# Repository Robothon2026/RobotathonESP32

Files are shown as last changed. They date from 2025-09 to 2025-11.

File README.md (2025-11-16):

# Robotathon ESP32
----Alternative Movement----
There are two different movement styles. Test both and see which feels better overall. 
1. Left joystick->left motor (current)
   Right joystick->right motor
2. Left joystick->both motors (commented out)
   Right joystick-> adjusts one side depending on x position

---- Line Automation----
 If correction is negative, move left by adjusting the left wheel slower while adjusitng the right wheel faster
 if correction is positive, move right by adjusting the right wheel slower while adjusitng the left wheel faster
 if correction is zero, move straight forward at full speed
 I decided to not use the invert sensors function because it is easers to just use 1,000 for black and 0 for white
 as if i use it the other way i would have to invert everything and also i wouldn't know how that would be able to work becuase
 *right now the lineHelper function works by multiplying the sensor values by the weights but if its 1,000 in the middle and 0 on white
 then the error would go based off the middle which i dont think would be as effecient and just more complicated then using 0
 for white and 1,000 for black

----Color Automation----
How to control
1. Switch to color automation.
2. Put robot over sample color.
4. It will continue to move until it finds the color again.

----Wall Automation----
This automation part is heavily heavily heavily dependant on thresholds.
Before even attempting, you have to ensure multiple different things work together.
1. I created TIME_90_DEGREES.
   You need to debug and find how long these numbers need to be for the robot to actually rotate 90 degrees. There's no actual way to tell the robot to turn a certain degree it has to be done manually.
2. In the wallAutomation() method, there are several variables you need to test as well.
   a. wallThreshold: This is the number (cm) until the robot should treat it as a wall.
   b. rightThreshold: This is the number (cm) that tells you how far it is from the right wall.
   c. speedAdjust: This is how much the motor will slow down when it's readjusting within walls.
   1. if no wall in front, move forward.
   2. If wall in front, check right sensor, if open path, rotate 90 degrees clockwise.
   3. Else (wall on right), rotate 90 degrees counter clockwise.
           Algorithm A: While moving forward, it should stay within the right bounds. If it's 
               within these bounds, just move forward. It may still drift a bit, but that's okay.
               If it's minor, I'll leave as is. If it's major, then I'll implement PD control
               to adjust the motors based off previous value. If it is out of these bounds, then
               adjust motors based off set values (not changing).
           Algorithm B: Just move forward without worrying about centering. If rotate90CW/CCW is
               implemented well enough, then no adjustments should be necessary.
           Algorithm C: Combination of A and B. Move forward normally, but before turning 90 degrees, 
               if previous right distance > current right distance, (getting closer to wall), then
               adjust delay for TIME_90_DEGREES so that it turns for longer. If previous right
               distance < current right distance, (getting farther away from wall), then adjust
               delay for TIME_90_DEGREES so that it turns for less time.
           Notes: Calculate the connection between delay time and angle turned. Use that to adjust
               TIME_90_DEGREES based off previous and current. Calculate previous and current by
               and make them a set time apart TIME_90_DEGREES. You can then use these two to create 
               a triangle and figure out the angle it's currently moving at. From there, you can 
               calculate how much to turn to be parallel to the wall after a turn. This assumes it 
               never hits the wall which should stand true, if not there's an error in the logic. 
               The delta time is TIME_90_DEGREES because you use this to turn 90 degrees, so after 
               calculating the angle you can easily figure out how much you need to adjust to stay 
               parallel.

----Notes----
2. Adjust color offset delay so robot is over the color. 
4. I use TOP_MOTOR_SPEED for a lot of things. Don't change this variable but make another one if you think it's too fast.
5. Calculate size of wheel and radius and create equation to automatically see how long it takes to do 90 degrees.
6. Design robot so it keeps turning towards the right and then it stops when its close enough (threshold).
7. Remove left sensor integration.

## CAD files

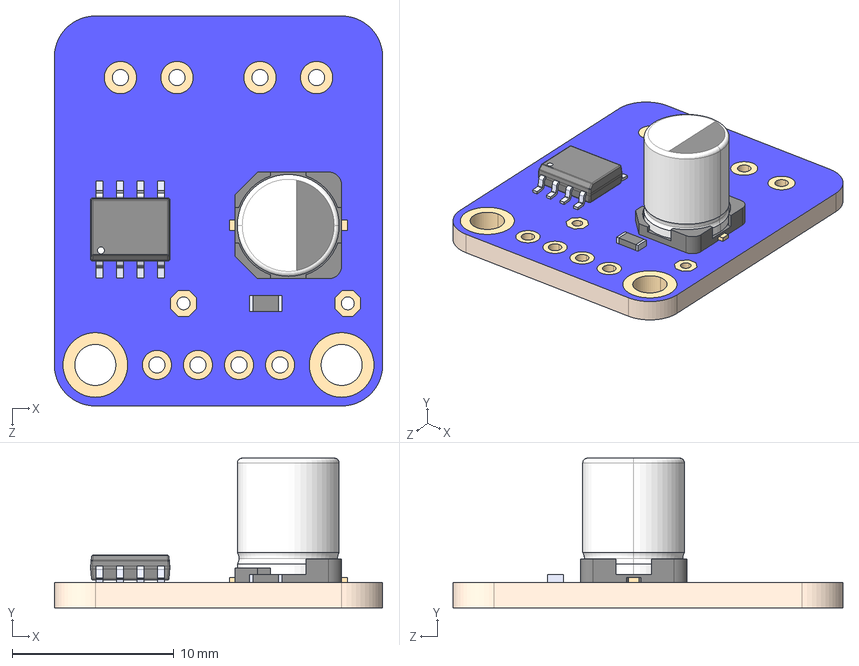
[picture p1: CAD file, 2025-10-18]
Robotathon_kicad/3190/3190.step
20.3 x 9.27 x 24.1 mm
Panasonic_D_22uF_63V_Panasonic_D_22uF_63V
DRV8871_DRV8871

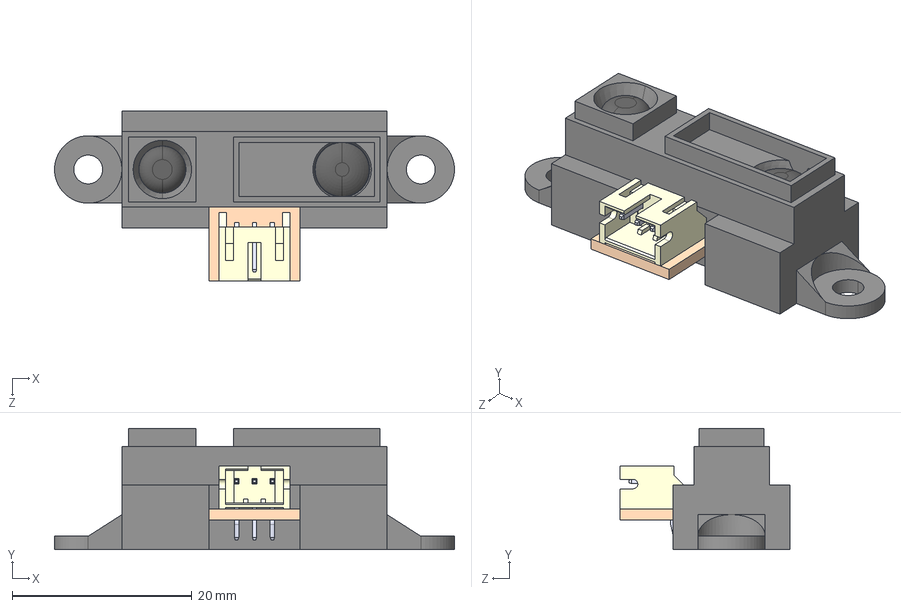
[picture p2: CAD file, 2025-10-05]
Robotathon_kicad/GP2Y0A21YK0F/GP2Y0A21YK0F.step
44.5 x 13.5 x 18.9 mm

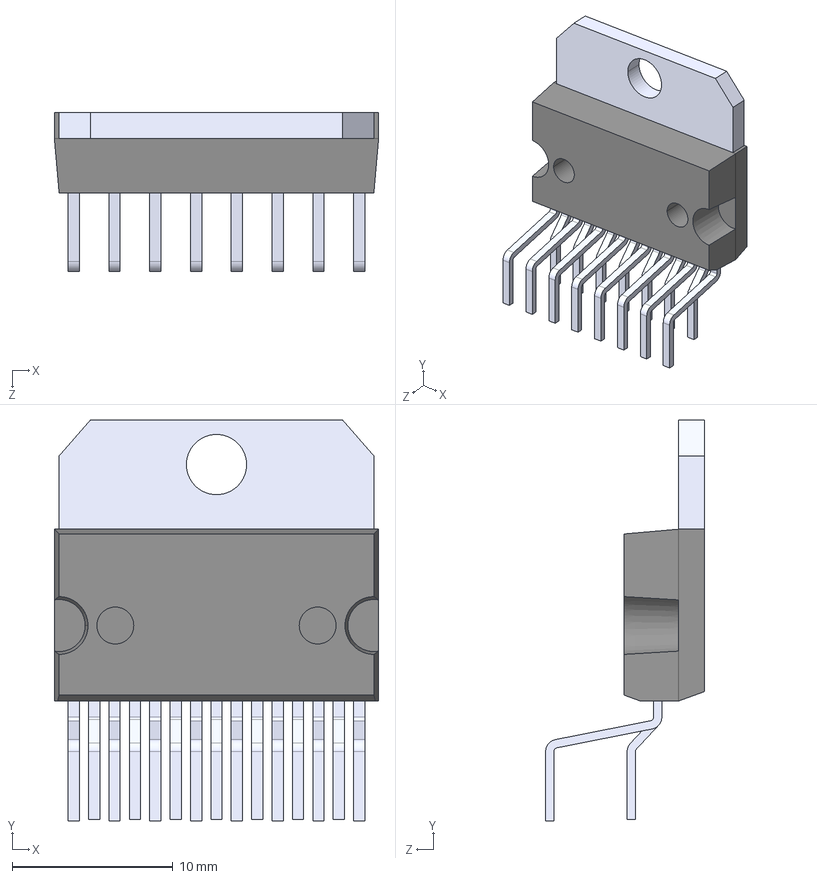
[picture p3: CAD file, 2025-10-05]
Robotathon_kicad/L298N/L298N.step
20.2 x 25.0 x 9.89 mm

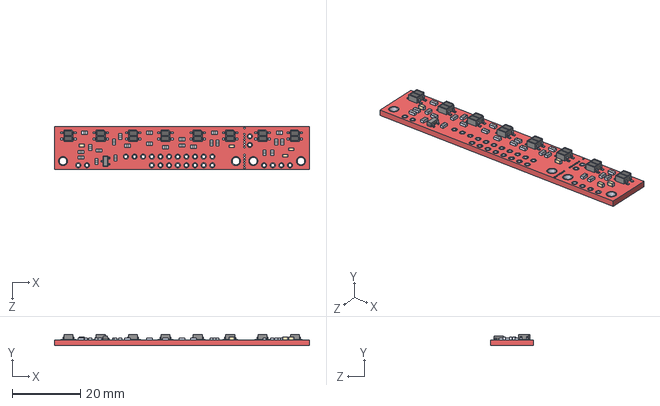
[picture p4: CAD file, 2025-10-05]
Robotathon_kicad/QTR-8A/QTR-8A.step
74.9 x 3.27 x 12.7 mm
QTR-8A_QTR-8A
QRE1113GR_QRE1113GR x 8

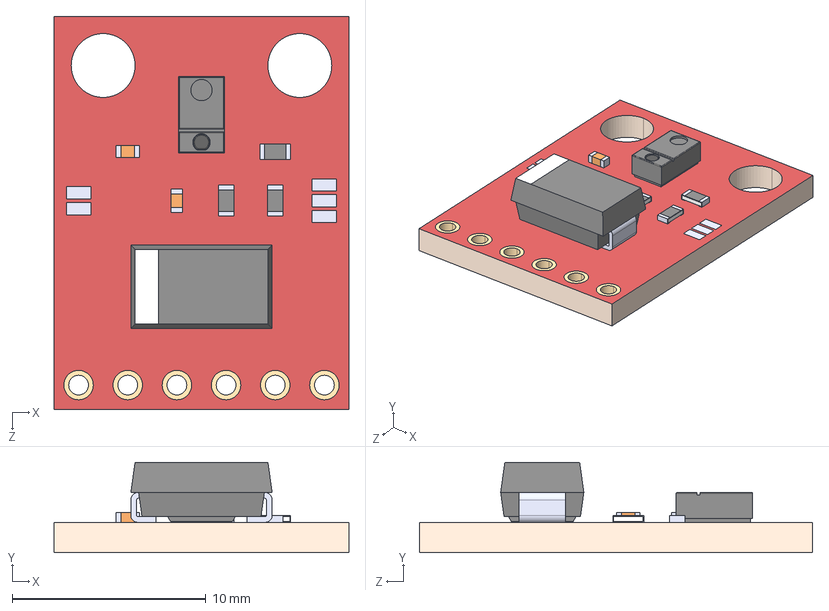
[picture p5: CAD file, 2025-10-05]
Robotathon_kicad/SEN-12787/SEN-12787.step
15.2 x 4.67 x 20.3 mm
SEN-12787_SEN-12787
100UF-10V-10%(TANT)_100UF-10V-10%(TANT)
APDS-9960_APDS-9960

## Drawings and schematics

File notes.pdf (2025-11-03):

# jopstick

14

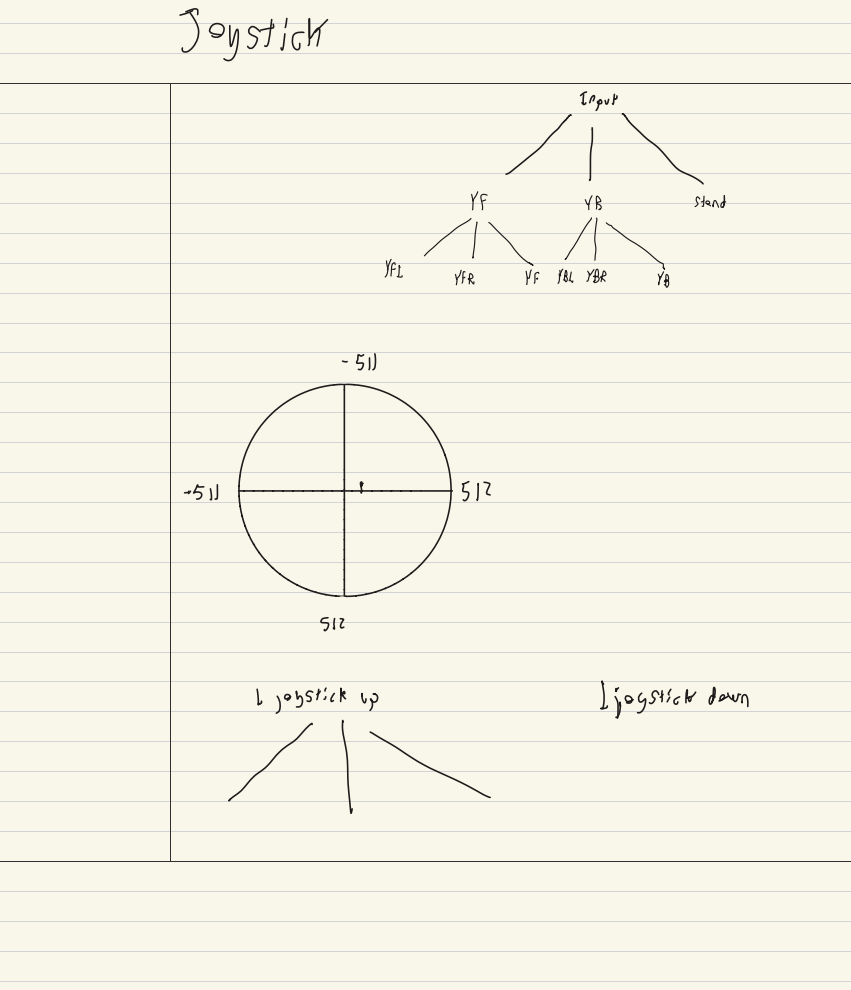
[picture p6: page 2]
Ifpur; ↓ joystick u; ↳ joysti down

e

# Automation

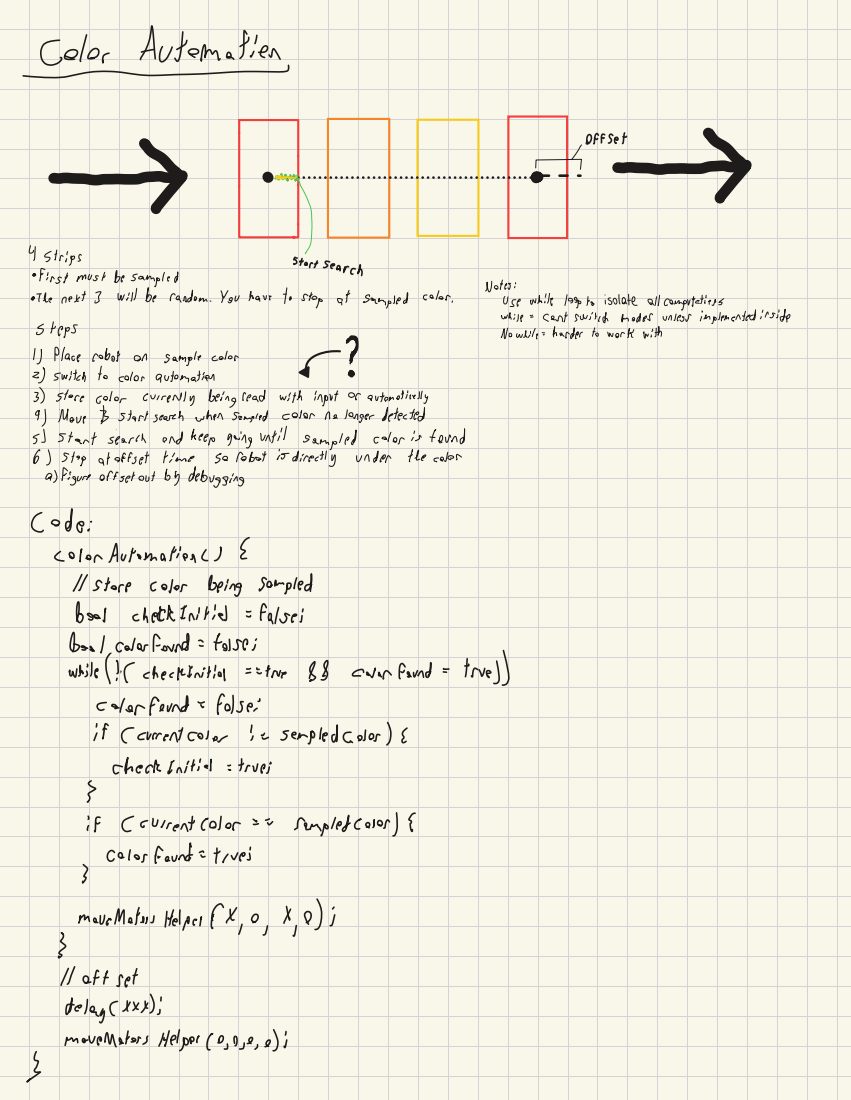
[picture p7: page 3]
oper D; ↑ strips; Start ·; Search first most be sampled; Notes :; The; next; will be random .; You; have to; stop; sampled; Salar.; use while los to; isolate all; computations wairp =; cast; ruited mater; unless implemented inside; Steps; No while harder to; work with; 1) Place; robot; sample; color; ) Switch; automation; 3) storerolor; evirently; being; read; with inout or; automatically -; Maup; start; seared when sampled; solar no langer detected -; i start searre; and beep pring until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

·

# MonAutomation

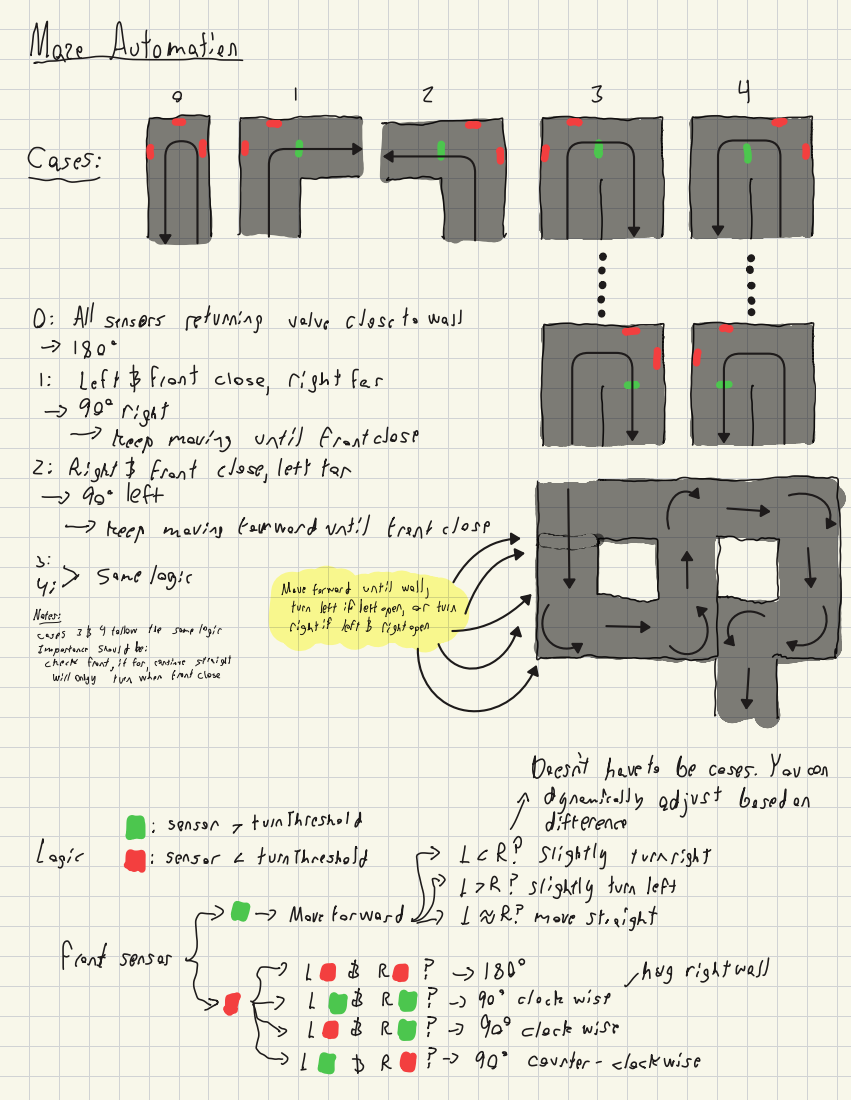
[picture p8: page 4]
All sensors; returning; value; close to; was; Left; front; close,; right; right for; keep moving; until front desp; Right; left for; left; Importance; check will; only; Samplegi; should; Roos; tallon; twin; if for; when; fle; continue; mavine; samples; striest; close; remmeramen; Move; turn; forward; left it left; until; open short; well,; gol; ori; trin; Doesn't; hare to; be cases.; You con; &premirely; afirst besoden; *: sensor - trin threshola; differenso; topir:; sensor a; turn threshold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

~......

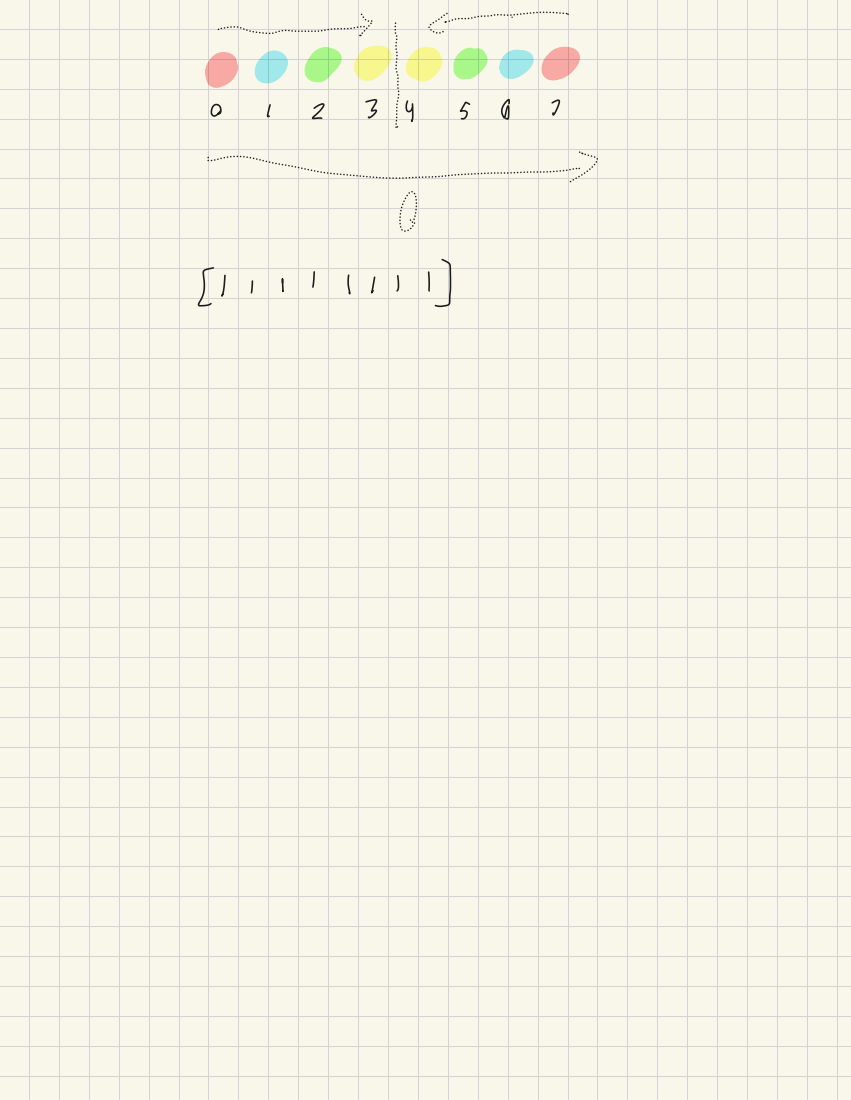
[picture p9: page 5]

MonAutomation | Gospe: | For wall, | R | not | no | right

## Topi

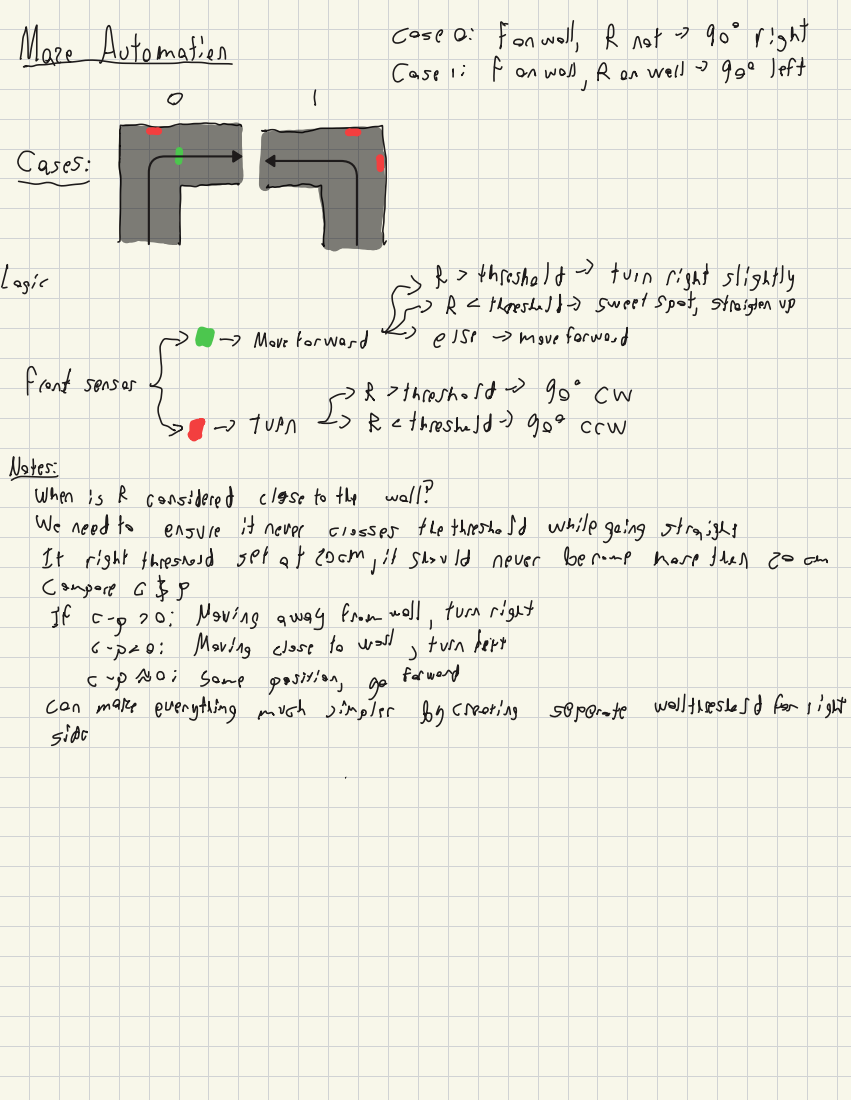
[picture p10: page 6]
Case; was; Ran well; doe /off; threshold; Fure; right; slightly; so & fooskid- swept soot,; streiten; front wonder ⁻ More forward --; - more for wast; furn; &threshold -; Rthreshed 400; Nater:; When; isR considered; elese to; the; wall; need; ensure; it never; crosses; whilp being; straight; # right throned opt; at seam ,; it should; never; become harp then; Campore a 0; spee:; Marine; away; from; well,; turn; rest; - gar:; dese; worl ,; turn hept; oto :; Samp; position,; For werf; can; make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

·

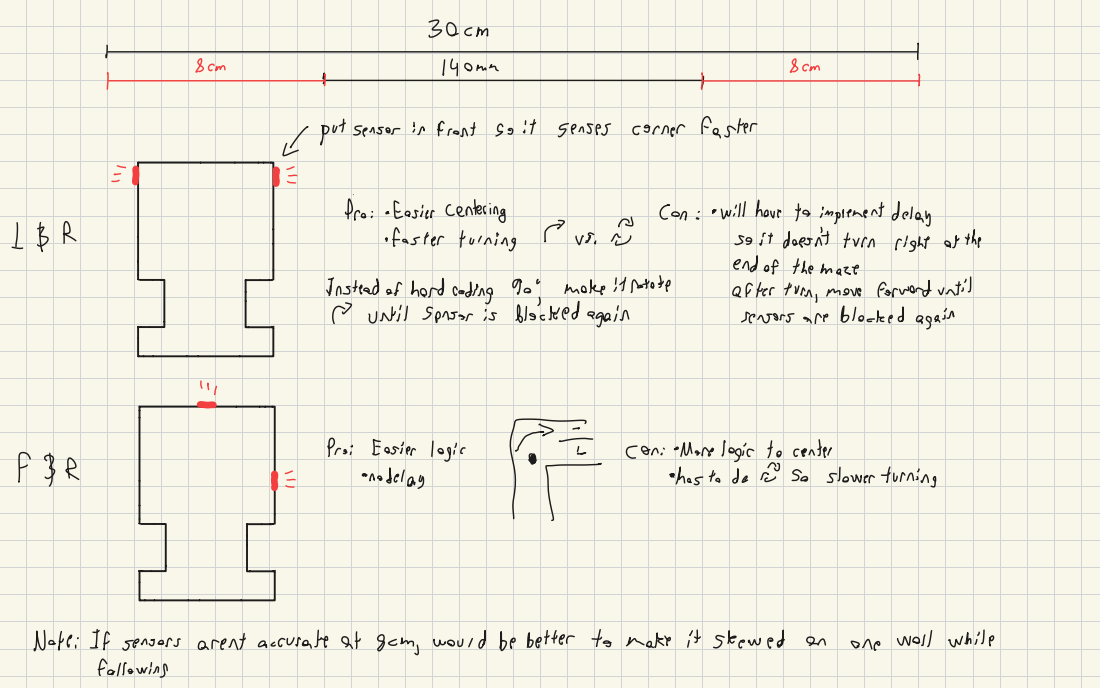
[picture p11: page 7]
1 Ome; ↓ put sensor; front; senses; corres faster; Pro :; Easier centering; Con :; -will; have; implement; delay ·faster; turning; doesn't; turn; rightafthe; end; the mase; Instead; hard rading; makeratets; after; forward until , more; until sprser is; blocked again; sensors are; W How; Note:; If sensors; arent accurate at bem; world; be better to; make; stewed; and; wall; while; following

# III

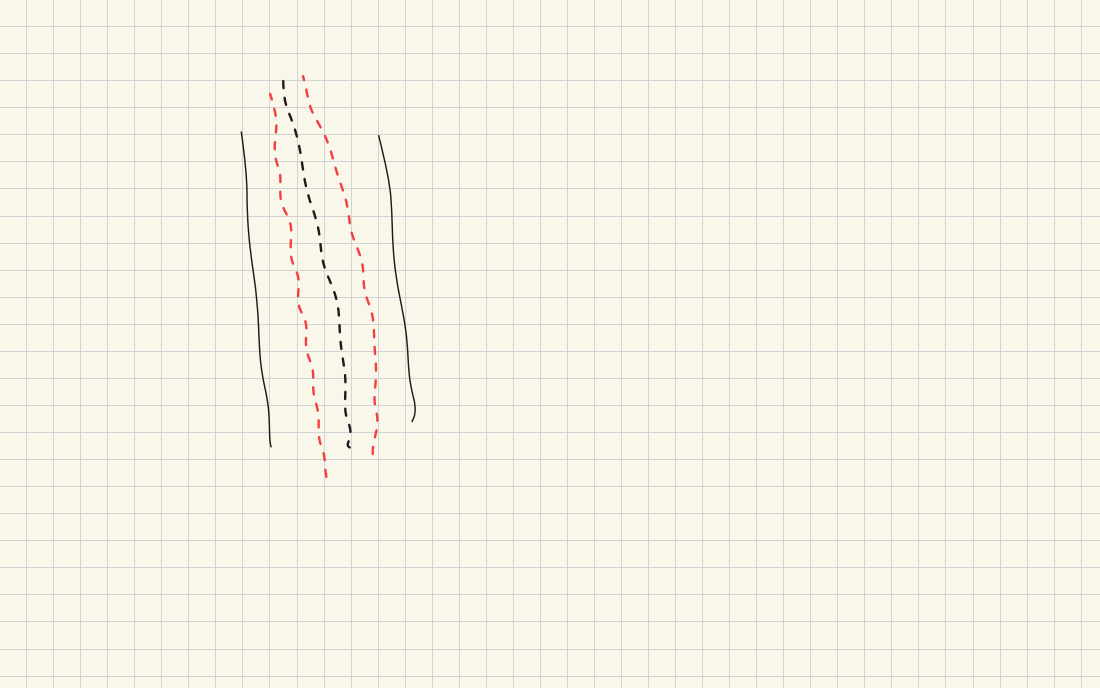
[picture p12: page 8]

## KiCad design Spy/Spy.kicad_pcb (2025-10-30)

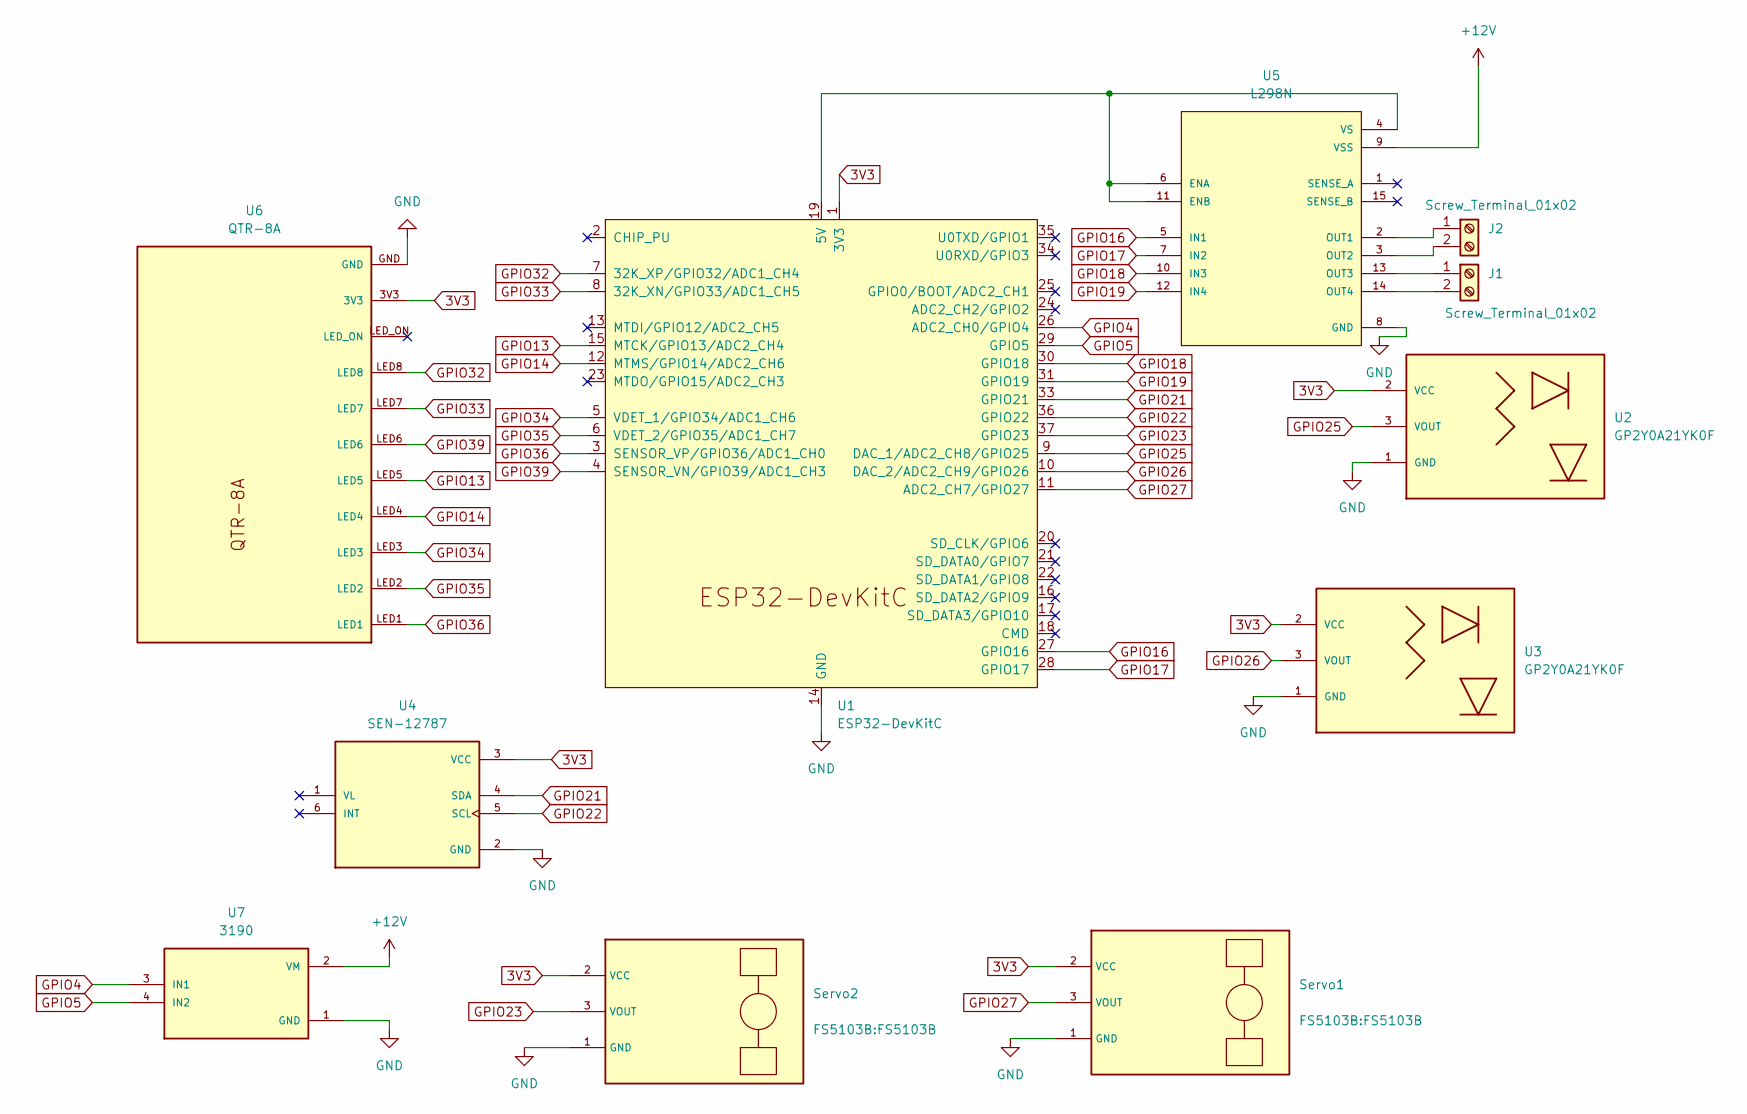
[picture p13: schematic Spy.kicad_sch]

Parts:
J1, J2: Screw_Terminal_01x02; PhoenixContact_MSTBA_2,5_2-G_1x02_P5.00mm_Horizontal
Servo1, Servo2: FS5103B
U1: ESP32-DevKitC
U2, U3: GP2Y0A21YK0F; 22-23-2031
U4: SEN-12787; MODULE_SEN-12787; PARTREV v10
U5: L298N; TO127P2020X500X2100-15
U6: QTR-8A
U7: 3190; MODULE_3190; PARTREV 2021-11-15

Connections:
3V3: Servo1.2 (VCC), Servo2.2 (VCC), U1.1 (3V3), U2.2 (VCC), U3.2 (VCC), U4.3 (VCC), U6.3V3
+12V: U5.9 (VSS), U7.2 (VM)
GND: Servo1.1 (GND), Servo2.1 (GND), U1.14 (GND), U1.32 (GND), U1.38 (GND), U2.1 (GND), U3.1 (GND), U4.2 (GND), U5.8 (GND), U6.GND, U7.1 (GND)
GPIO4: U1.26 (ADC2_CH0/GPIO4), U7.3 (IN1)
GPIO5: U1.29 (GPIO5), U7.4 (IN2)
GPIO13: U1.15 (MTCK/GPIO13/ADC2_CH4), U6.LED5
GPIO14: U1.12 (MTMS/GPIO14/ADC2_CH6), U6.LED4
GPIO16: U1.27 (GPIO16), U5.5 (IN1)
GPIO17: U1.28 (GPIO17), U5.7 (IN2)
GPIO18: U1.30 (GPIO18), U5.10 (IN3)
GPIO19: U1.31 (GPIO19), U5.12 (IN4)
GPIO21: U1.33 (GPIO21), U4.4 (SDA)
GPIO22: U1.36 (GPIO22), U4.5 (SCL)
GPIO23: Servo2.3 (VOUT), U1.37 (GPIO23)
GPIO25: U1.9 (DAC_1/ADC2_CH8/GPIO25), U2.3 (VOUT)
GPIO26: U1.10 (DAC_2/ADC2_CH9/GPIO26), U3.3 (VOUT)
GPIO27: Servo1.3 (VOUT), U1.11 (ADC2_CH7/GPIO27)
GPIO32: U1.7 (32K_XP/GPIO32/ADC1_CH4), U6.LED8
GPIO33: U1.8 (32K_XN/GPIO33/ADC1_CH5), U6.LED7
GPIO34: U1.5 (VDET_1/GPIO34/ADC1_CH6), U6.LED3
GPIO35: U1.6 (VDET_2/GPIO35/ADC1_CH7), U6.LED2
GPIO36: U1.3 (SENSOR_VP/GPIO36/ADC1_CH0), U6.LED1
GPIO39: U1.4 (SENSOR_VN/GPIO39/ADC1_CH3), U6.LED6
unnamed: J1.1, U5.13 (OUT3)
unnamed: J1.2, U5.14 (OUT4)
unnamed: J2.1, U5.2 (OUT1)
unnamed: J2.2, U5.3 (OUT2)
unnamed: U1.19 (5V), U5.4 (VS), U5.6 (ENA), U5.11 (ENB)

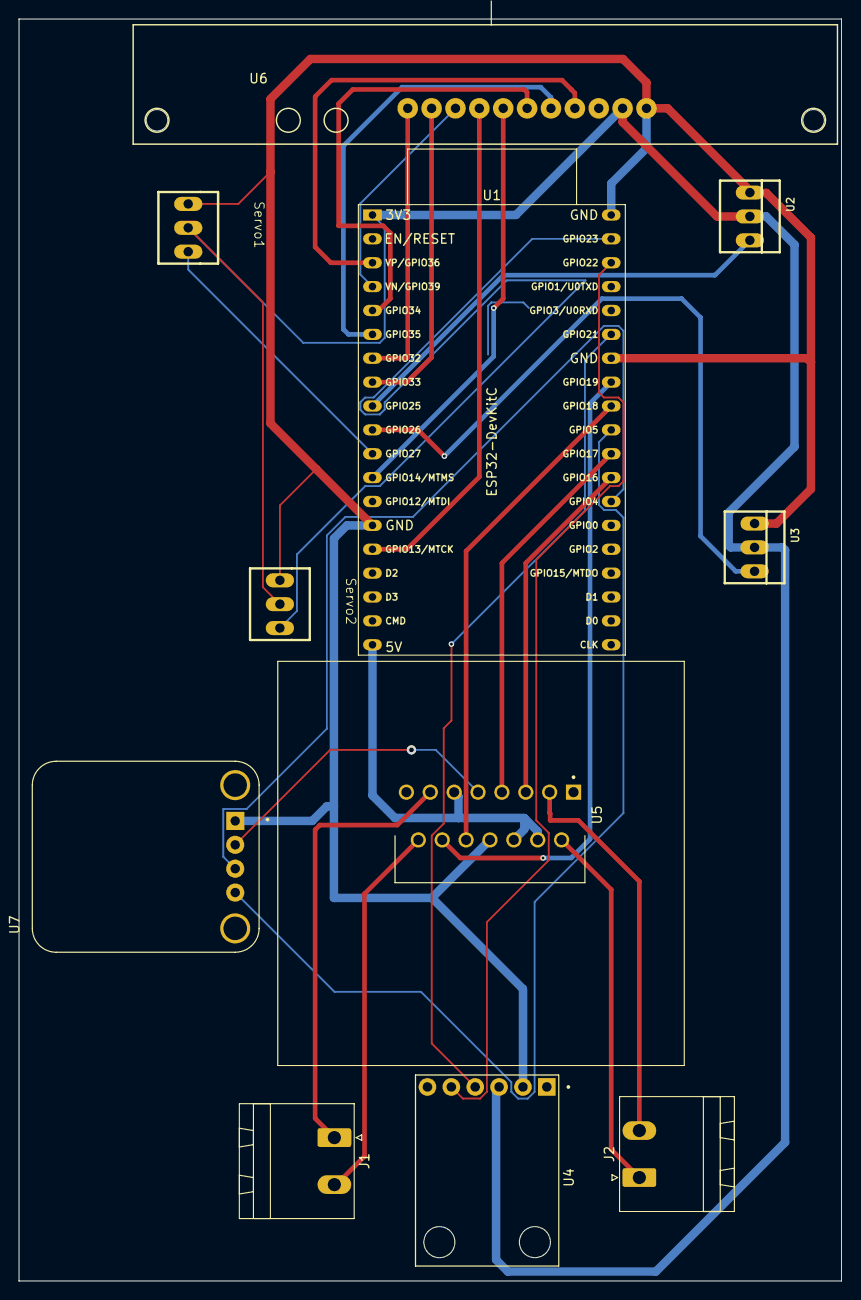
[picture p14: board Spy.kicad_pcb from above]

Board: 2 copper layers, 87.5 x 134.2 mm, 11 parts (0 on the bottom side), 28 nets.

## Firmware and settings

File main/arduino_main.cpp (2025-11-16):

// SPDX-License-Identifier: Apache-2.0
// Copyright 2021 Ricardo Quesada
// http://retro.moe/unijoysticle2

#include "sdkconfig.h"
#include <Arduino.h>
#include <Bluepad32.h>
#include <uni.h>
#include "controller_callbacks.h"
#include <QTRSensors.h> // line sensor library
#include <ESP32SharpIR.h> // ir sensor library
#include <Wire.h>
#include <Arduino_APDS9960.h> // color sensor library
#include <bits/stdc++.h>
#include <ESP32Servo.h>


#define ONBOARD_LED_PIN 2 // LED pin

#define IN1 19 // right motor pins
#define IN2 18

#define IN3 17 // left motor pins
#define IN4 16  

#define IN5 4 // launch motor pins
#define IN6 5

const uint8_t LINE_FOLLOW_PINS[] = {36, 35, 34, 14, 13, 39, 33, 32}; // line sensor pins

#define LEFT_IR_PIN 0 // ir pin
#define FRONT_IR_PIN 25 // ir pin
#define RIGHT_IR_PIN 26 // ir pin

#define APDS9960_INT_PIN 0 // color pins
#define I2C_SDA_PIN 21
#define I2C_SCL_PIN 22

#define ANGLE_SERVO_PIN 23 // angle servo pin


const char* const MODES[] = {"Manual", "Color automation", "Wall automation", "Line automation"};
const uint8_t TOP_MOTOR_SPEED = 255;

const uint8_t MANUAL = 0;
const uint8_t COLOR_AUTOMATION = 1;
const uint8_t WALL_AUTOMATION = 2;
const uint8_t LINE_AUTOMATION = 3;

const int8_t NONE = -1;

uint8_t currentMode = 0; // current mode for robot
extern ControllerPtr myControllers[BP32_MAX_GAMEPADS]; // controller



//------------------------------------------------------------------------------------------------//
//------------------------------------------<< HELPERS >>-----------------------------------------//
//------------------------------------------------------------------------------------------------//

/*
 * Cleans terminal to debug easier.
 */
void cleanTerminalSimple() {
    for (uint8_t i = 0; i < 25; i++) {
        Console.println();
    }
}

/*
 * Alternative way to clean easier.
 * Removes current line.
 */
void cleanTerminalAdvancedSeq1() {
    Console.print('\r');
    Console.print("\x1B[2K");
}

/*
 * Sets cursor back to beginning for next clear call.
 */
void cleanTerminalAdvancedSeq2() {
    Console.write('\r');
}

/*
 * Sets current mode based on controller input.
 * @param ctl pointer to controller
 */
void setMode(ControllerPtr ctl) {
    if (ctl->b()) {
        currentMode = MANUAL;
    } else if (ctl->a()) {
        currentMode = COLOR_AUTOMATION;
    } else if (ctl->x()) {
        currentMode = WALL_AUTOMATION;
    } else if (ctl->y()) {
        currentMode = LINE_AUTOMATION;
    }
}

//------------------------------------------------------------------------------------------------//
//---------------------------------------<< MOTOR MOVEMENT >>-------------------------------------//
//------------------------------------------------------------------------------------------------//

const uint16_t MAX_JOYSTICK_INPUT = 512;


void moveMotorsHelper(int leftSpeedForward, int leftSpeedBackward, int rightSpeedForward, 
    int rightSpeedBackward);


/*
 * Sets up the motor pins as outputs.
 */
void motorSetup() {
    pinMode(IN1, OUTPUT); // left motor
    pinMode(IN2, OUTPUT);
    pinMode(IN3, OUTPUT); // right motor
    pinMode(IN4, OUTPUT);
}

/*
 * Handles the movement of the robot.
 * Left joystick controls left motor and right joystick controls right motor.
 * @param ctl pointer to controller
 */
void moveMotorsAdvanced(ControllerPtr ctl) {
    int16_t lY = ctl->axisY(); // left joystick Y axis
    uint8_t aLY = abs(lY) * TOP_MOTOR_SPEED / MAX_JOYSTICK_INPUT; // adjusted left joystick 
                                                      // Y axis for speed input [0, TOP_MOTOR_SPEED]
    int16_t rY = ctl->axisRY();// right joystick Y axis
    uint8_t aRY = abs(rY) * TOP_MOTOR_SPEED / MAX_JOYSTICK_INPUT; // adjusted right joystick Y axis 
                                                             // for speed input [0, TOP_MOTOR_SPEED]

    bool lForward = (lY <= -200); // determine if left joystick is moving forward
    bool lBackward = (lY >= 200); // determine if left joystick is moving backwards
    bool rForward = (rY <= -200);
    bool rBackward = (rY >= 200);

    if (lForward) { // if left joystick is forward, move motor forward at adjusted speed
        analogWrite(IN1, aLY);
        analogWrite(IN2, 0);
    } else if (lBackward) {
        analogWrite(IN1, 0);
        analogWrite(IN2, aLY);
    } else { // stop
        analogWrite(IN1, 0);
        analogWrite(IN2, 0);
    }

    if (rForward) { // if right joystick is forward, move motor forward at adjusted speed
        analogWrite(IN3, aRY);
        analogWrite(IN4, 0);
    } else if (rBackward) {
        analogWrite(IN3, 0);
        analogWrite(IN4, aRY);
    } else { // stop
        analogWrite(IN3, 0);
        analogWrite(IN4, 0);
    }
}

/*
 * Handles the movement of the robot.
 * Left joystick controls both motors and the right joystick turns it to one direction.
 * @param ctl pointer to controller
 */
void moveMotorsSimple(ControllerPtr ctl) {
    int16_t lY = ctl->axisY(); // left joystick y-value
    uint8_t aLY = abs(lY) * TOP_MOTOR_SPEED / MAX_JOYSTICK_INPUT; // adjusted left joystick Y axis 
                                                             // for speed input [0, TOP_MOTOR_SPEED]
    int16_t rX = ctl->axisRX(); // right joystick x-value
    uint8_t aRX = abs(rX) * TOP_MOTOR_SPEED / MAX_JOYSTICK_INPUT; // adjusted right joystick X axis 
                                                             // for speed input [0, TOP_MOTOR_SPEED]
    bool lB = ctl->l1(); // left bumper
    bool rB = ctl->r1(); // right bumper

    uint8_t motorAdjustment = max(0, aLY - aRX); // adjusts motor speed for either side
    bool forward = (lY <= -200); // determine if left joystick is moving forward
    bool backward = (lY >= 200);
    bool left = (rX <= -30); // determine if right joystick is pushed left
    bool right = (rX >= 30);

    if (forward) {
        if (left) {
            moveMotorsHelper(motorAdjustment,0, aLY, 0);
        } else if (right) {
            moveMotorsHelper(aLY, 0, motorAdjustment, 0);
        } else {
            moveMotorsHelper(aLY, 0, aLY, 0);
        }
    } else if (backward) {
        if (left) {
            moveMotorsHelper(0, motorAdjustment, 0, aLY);
        } else if (right) {
            moveMotorsHelper(0, aLY, 0, motorAdjustment);
        } else {
            moveMotorsHelper(0, aLY, 0, aLY);
        }
    } else { // left joystick netural (within -200, 200)
        if (lB) { // spin counter-clockwise
            moveMotorsHelper(0, TOP_MOTOR_SPEED, TOP_MOTOR_SPEED, 0);
        } else if (rB) { // spin clockwise
            moveMotorsHelper(TOP_MOTOR_SPEED, 0, 0, TOP_MOTOR_SPEED);
        } else { // standstill
            moveMotorsHelper(0, 0, 0, 0);
        }
    }
}

/*
 * Prints all button values for the controller.
 * @param ctl pointer to controller
 */
void dumpGamepad(ControllerPtr ctl) {
    Console.printf(
        "DPAD: %2d A: %2d B: %2d X: %2d Y: %2d LX: %4d LY: %4d RX: %4d RY: %4d L1: %2d R1: %2d \
        L2: %2d R2: %2d\n",
        ctl->dpad(),        // D-pad
        ctl->a(),           // Letter buttons
        ctl->b(),
        ctl->x(),
        ctl->y(),
        ctl->axisX(),        // (-511 - 512) left X Axis
        ctl->axisY(),        // (-511 - 512) left Y axis
        ctl->axisRX(),       // (-511 - 512) right X axis
        ctl->axisRY(),       // (-511 - 512) right Y axis
        ctl->l1(),           // Bumpers
        ctl->r1(),
        ctl->l2(),
        ctl->r2()
    );
}

/*
 * Helper to simplify motor control.
 * Takes in four values: left speed f/b, and right speed f,b
 * @param leftSpeedForward left motor speed forward
 * @param leftSpeedBackward left motor speed backwards
 * @param rightSpeedForward right motor speed forward
 * @param rightSpeedBackward right motor speed backwards
 */
void moveMotorsHelper(int leftSpeedForward, int leftSpeedBackward, int rightSpeedForward, 
    int rightSpeedBackward) {
    analogWrite(IN1, leftSpeedForward);
    analogWrite(IN2, leftSpeedBackward);
    analogWrite(IN3, rightSpeedForward);
    analogWrite(IN4, rightSpeedBackward);
}

//------------------------------------------------------------------------------------------------//
//---------------------------------------<< MOTOR LAUNCHER >>-------------------------------------//
//------------------------------------------------------------------------------------------------//

const uint8_t MIN_SPEED = 55;

bool launchMotor = false;
bool launchMotorRamped = false;

float speedMultiplier = 0.67; // range is .22 to 1.0
uint8_t maxLauncherSpeed = constrain((int)(TOP_MOTOR_SPEED * speedMultiplier), 55, 255);

int rampTimeMillis = 1000;


void rampUpLaunchMotor();
void rampDownLaunchMotor();
void moveLaunchMotorHelper(int speedForward, int speedBackward);


/*
 * Setup for launch motor.
 */
void launchMotorSetup() {
    pinMode(IN5, OUTPUT);
    pinMode(IN6, OUTPUT);
}

/* 
 * Checks to see if launch motors need to be ramped up/down or neither.
 * @param ctl pointer to controller
 */
void checkLaunchMotor(ControllerPtr ctl) {
    launchMotor = (ctl->r2()) ? true : false;

    if (launchMotor && !launchMotorRamped) {
        rampUpLaunchMotor();
        launchMotorRamped = true;
    } else if (!launchMotor && launchMotorRamped) {
        rampDownLaunchMotor();
        launchMotorRamped = false;
    }
}


/*
 * Ramp launch motors up so it doens't reach max speed instantly.
 */
void rampUpLaunchMotor() {
    int numSteps = maxLauncherSpeed - MIN_SPEED;

    for (int i = MIN_SPEED; i <= numSteps; i++) {
        moveLaunchMotorHelper(i, 0);
        delay(rampTimeMillis / numSteps);
    }
}

/*
 * Ramp down launch motors so it doesn't stop instantly.
 */
void rampDownLaunchMotor() {
    uint8_t initialSpeed = maxLauncherSpeed;
    int numSteps = initialSpeed - MIN_SPEED;

    for (uint8_t i = initialSpeed; i >= MIN_SPEED; i--) {
        moveLaunchMotorHelper(i, 0);
        delay(rampTimeMillis / numSteps);
    }

    moveLaunchMotorHelper(0, 0);
}

/*
 * Helper to simplify launch motor control.
 * @param speedForward motor speed forward
 * @param speedBackward motor speed backward
 */
void moveLaunchMotorHelper(int speedForward, int speedBackward) {
    analogWrite(IN5, speedForward);
    analogWrite(IN6, speedBackward);
}

//------------------------------------------------------------------------------------------------//
//-------------------------------------------<< SERVO >>------------------------------------------//
//------------------------------------------------------------------------------------------------//

Servo angleServo;


const uint8_t ANGLE_CLOSED = 0;
const uint8_t ANGLE_OPEN = 60;

uint8_t angle = 0; // current angle of angleServo


/*
 * Setups up the angle and collection servo.
 */
void angleServoSetup() {
    angleServo.attach(ANGLE_SERVO_PIN);
    angle = angleServo.read(); // current angle
}

/*
 * Handles the movement of the angle servo.
 * Dpad up and down control the angle of the servo. (N U D R L) -> (0, 1, 2, 4, 8).
 * @param ctl pointer to controller
 */
void moveAngleServo(ControllerPtr ctl) {
    uint8_t dpad = ctl->dpad();

    if (dpad == DPAD_UP) {
        angleServo.write(ANGLE_OPEN);
    } else if (dpad == DPAD_DOWN) {
        angleServo.write(ANGLE_CLOSED);
    }
}

//------------------------------------------------------------------------------------------------//
//--------------------------------------<< LINE AUTOMATION >>-------------------------------------//
//------------------------------------------------------------------------------------------------//

QTRSensors qtr;
const uint8_t NUM_LINE_SENSORS = sizeof(LINE_FOLLOW_PINS) / sizeof(LINE_FOLLOW_PINS[0]);
uint16_t lineArray[NUM_LINE_SENSORS];


float kP= 0.5; // proportional constant
float kD = 10.0; // derivative constant
float kI = 0; // integral constant
float lastEror = 0; // last error for derivative calculation
float sum = 0; // sum of errors for integral calculation

bool pressedPU = false;
bool pressedPD = false;
bool pressedDU = false;
bool pressedDD = false;

int16_t lineThreshold = 950;
uint8_t lineSpeed = TOP_MOTOR_SPEED;
uint8_t ricochet = 0;
int8_t lastRemembered = -1;
uint8_t maxRicochet = 10;

bool lineCalibrated = false;


void calibrateLineSensors();
float lineHelper();
void updatePID(ControllerPtr ctl);
void setPressed(bool val1, bool val2, bool val3, bool val4);
bool checkInBetween();


/*
 * Sets up the line following sensors.
 */
void lineSetup() {
    qtr.setTypeAnalog();
    qtr.setSensorPins(LINE_FOLLOW_PINS, NUM_LINE_SENSORS);
}

/*
 * Fabian's Algorithm
 * Handles the line following automation.
 * @param ctl pointer to controller
 */
void lineAutomationA(ControllerPtr ctl) {
    updatePID(ctl);
    uint8_t speed = TOP_MOTOR_SPEED;
    float correction = lineHelper(); // correction for the lineHelper that will fix the robot's path
    correction = constrain(correction, -speed, speed);
    uint8_t leftSpeed = constrain((int)(speed + correction), 0, TOP_MOTOR_SPEED);
    uint8_t rightSpeed = constrain((int)(speed - correction), 0, TOP_MOTOR_SPEED);
    moveMotorsHelper(leftSpeed ,0 ,rightSpeed ,0); // move motors with correction applied to speed
}

/*
 * Handles the line following automation.
 * Three cases:
 *     1. no sensor activated -> move forward
 *     2. first sensor activated -> move left
 *     3. last sensor activated -> move right
 *     4. no sensor activated -> spin in certain direction
 */
void lineAutomationB() {
    uint16_t firstSensor = lineArray[NUM_LINE_SENSORS - NUM_LINE_SENSORS];
    uint16_t lastSensor = lineArray[NUM_LINE_SENSORS - 1];
    bool firstOnLine = firstSensor > lineThreshold;
    bool lastOnLine = lastSensor > lineThreshold;
    bool lineInBetween = checkInBetween();
    
    if (firstOnLine && ricochet < maxRicochet) { // line on first -> turn right
        moveMotorsHelper(0, lineSpeed, lineSpeed, 0);
        ricochet++;
        lastRemembered = 0;
    } else if (lastOnLine && ricochet < maxRicochet) { // line on last -> turn left
        moveMotorsHelper(lineSpeed, 0, 0, lineSpeed);
        ricochet++;
        lastRemembered = 1;
    } else if (lineInBetween || ricochet >= maxRicochet) { // on line/ricochet -> move forward
        moveMotorsHelper(lineSpeed, 0, lineSpeed, 0);
        ricochet = 0;
    } else { // nothing sensed -> turn in last known direction

        if (lastRemembered == 0) { // last remembered is first
            moveMotorsHelper(0, 0, lineSpeed, 0);
        } else if (lastRemembered == 1) { // last remembered is last
            moveMotorsHelper(lineSpeed, 0, 0, 0);
        }

        ricochet = 0;
    }
}

/*
 * Checks if the line is present betwen the 2nd and 7th sensor.
 * @return true if line is present, else false.
 */
bool checkInBetween() {
    for (uint8_t i = 1; i < NUM_LINE_SENSORS - 1; i++) {

        if (lineArray[i] > lineThreshold) {
            return true;
        }
    }

    return false;

}

/*
 * Prints the line sensor values.
 */
void lineDebug() {
    for (uint8_t i = 0; i < NUM_LINE_SENSORS; i++) {
        Console.printf("%d  ", lineArray[i]);
    }
}

/*
 * Updates lineArray with new values.
 */
void updateLine() {
    qtr.readLineBlack(lineArray);
}

/*
 * Helper method that calculates error and PID.
 * @return how much to correct using PID
 */
float lineHelper() {
    float error = 0;
    int wPosition = 0;
    int16_t weights[] = {-3000, -2000, -1000, -500, 500, 1000, 2000, 3000}; // Adjust weights based 
                                                                            // on number of sensors

    for(uint8_t i = 0; i < NUM_LINE_SENSORS; i++) { // for loop to go through all sensors
        wPosition += lineArray[i] * weights[i];   // calculates the weighted error with the value of   
    }     // the sensor. Example: if leftmost sensor is on black (1000) and all others are white (0)
    // then error = 0 * -3 + 1,000 * -2 +  1,000 * -1 + 0 * 0 + 0* 0 + 0 * 1 + 0 * 2 + 0 * 3 = -3000
    error = wPosition / 3000; // Normalize error by diving by the highest sensor value that is 1000;
    float P = kP * error; // equation for the porpotional term for the immediate correction
    float D = kD * (error - lastEror); // equation for the derivative term for appliying a small 
                                       // brake on the porpotional term
    sum = sum + error; // sum of all errors up to now for integral term to use to track long term
                       // errors over the course
    float I = kI * sum; // equation for the integral term to correct for long term error and apply 
                        // small amount of correction
                      // The integral term is very small and only affects the robot if a long and
                      // difficult course.
    lastEror = error; // Store current error for the next calculation for the derivative term 
    return P + D + I; // return the added up corrections into one value
}

/*
 * Calibrates line sensors over 250 iterations. 
 * Increase if need be.
 */
void calibrateLineSensors() {
    int16_t numSteps = 250;
    uint8_t calibrateDelayMillis = 20;

    for (uint8_t i = 0; i < numSteps; i++) {
        qtr.calibrate();
        delay(calibrateDelayMillis);
    }
}

/*
 * All in one sequence to complete calibration.
 */
void startCalibration() {
    moveMotorsHelper(TOP_MOTOR_SPEED, 0, 0, TOP_MOTOR_SPEED);
    calibrateLineSensors();
    moveMotorsHelper(0, 0, 0, 0);
    lineCalibrated = true;
    currentMode = MANUAL;
}

/*
 * Updates PID values remotely using buttons. Easy switching.
 * @param ctl pointer to controller 
 */
void updatePID(ControllerPtr ctl) {
    uint8_t dpad = ctl->dpad();

    if (dpad == DPAD_UP && !pressedPU) {
        kP++;
        setPressed(true, false, false, false);
    } else if (dpad == DPAD_DOWN && !pressedPD) {
        kP--;
        setPressed(false, true, false, false);
    } else if (dpad == DPAD_RIGHT && !pressedDU) {
        kD++;
        setPressed(false, false, true, false);
    } else if (dpad == DPAD_LEFT && !pressedDD) {
        kD--;
        setPressed(false, false, false, true);
    } else {
        setPressed(false, false, false, false);
    }
}

/*
 * Ensures tapping a button doesn't increase value significantly.
 */
void setPressed(bool val1, bool val2, bool val3, bool val4) {
    pressedPU = val1;
    pressedPD = val2;
    pressedDU = val3;
    pressedDD = val4;
}


//------------------------------------------------------------------------------------------------//
//-------------------------------------<< COLOR AUTOMATION >>-------------------------------------//
//------------------------------------------------------------------------------------------------//

TwoWire I2C_0 = TwoWire(0);// color
APDS9960 apds = APDS9960(I2C_0, APDS9960_INT_PIN);
const int I2C_FREQUENCY = 100000; // I2C frequency for color sensor


const uint8_t NUM_COLORS = 4;
const uint8_t RED = 0;
const uint8_t GREEN = 1;
const uint8_t BLUE = 2;
const uint8_t ALPHA = 3;

float redAdjust = 1.43;
float greenAdjust = 1.25;

int colorArray[NUM_COLORS]; // array holding information for r, g, b, a

int8_t sampleColor = NONE; // saves red, green, or blue (no other colors)
int8_t currentColor = NONE;

bool checkInitial = false; // value to check if we moved off the color
bool colorFound = false; // value to check if we found the color again
bool sampled = false;

uint8_t redInARow = 0;
uint8_t greenInARow = 0;
uint8_t blueInARow = 0;
uint8_t rangeThreshold = 10;
uint8_t inARowThreshold = 3;


int recordColorOverCheck();
int recordColorMultiplierCheck();
int recordColorThresholdCheck();
int recordColorRecordedCheck();
void resetColorVariables();
void updateInARow(int val1, int val2, int val3);

/*
 * Sets up the color sensor and I2C communication.
 */
void colorSetup() {
    I2C_0.begin(I2C_SDA_PIN, I2C_SCL_PIN, I2C_FREQUENCY);
    apds.setInterruptPin(APDS9960_INT_PIN);
    apds.begin();
}
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
void loop() {
    vTaskDelay(1); // Ensures WDT does not get triggered when no controller is connected
    BP32.update();
    bool debug = false;
    bool automate = true;
    for (auto myController : myControllers) { // Only execute code when controller is connected
        if (myController && myController->isConnected() && myController->hasData()) {

            setMode(myController);
            cleanTerminalSimple();
            digitalWrite(ONBOARD_LED_PIN, HIGH);

            if (debug) Console.printf("Current mode: %s ------- ", MODES[currentMode]);

            switch (currentMode) {
                case MANUAL:
                    if (sampled) resetColorVariables();

                    if (automate) {
                        checkLaunchMotor(myController);
                        moveMotorsSimple(myController);
                        moveAngleServo(myController);
                    }

                    if (debug) dumpGamepad(myController);

                    break;
                case COLOR_AUTOMATION:
                    updateColor();

                    if (automate) colorAutomation(myController);

                    if (debug) colorDebug();

                    break;
                case WALL_AUTOMATION:
                    updateIR();

                    if (automate) wallAutomationNoCorrectionFR();

                    if (debug) wallDebugSimple();

                    break;
                case LINE_AUTOMATION:
                    if (!lineCalibrated) startCalibration();

                    updateLine();

                    if (automate) lineAutomationB();

                    if (debug) lineDebug();
                    
                    break;
            }
            digitalWrite(ONBOARD_LED_PIN, LOW);
        }
    }
}

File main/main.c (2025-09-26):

/*

ROBOTATHON PEOPLE START IN arduino_main.cpp!!! This file just initializes the Arduino platform and Bluepad32 library!

*/


// SPDX-License-Identifier: Apache-2.0
// Copyright 2019 Ricardo Quesada
// http://retro.moe/unijoysticle2

#include "sdkconfig.h"

#include <stddef.h>

// BTstack related
#include <btstack_port_esp32.h>
#include <btstack_run_loop.h>
#include <btstack_stdio_esp32.h>

// Bluepad32 related
#include <arduino_platform.h>
#include <uni.h>



//
// Autostart
//
#if CONFIG_AUTOSTART_ARDUINO
void initBluepad32() {
#else
int app_main(void) {
#endif  // !CONFIG_AUTOSTART_ARDUINO
    // hci_dump_open(NULL, HCI_DUMP_STDOUT);

// Don't use BTstack buffered UART. It conflicts with the console.
#ifndef CONFIG_ESP_CONSOLE_UART_NONE
#ifndef CONFIG_BLUEPAD32_USB_CONSOLE_ENABLE
    btstack_stdio_init();
#endif  // CONFIG_BLUEPAD32_USB_CONSOLE_ENABLE
#endif  // CONFIG_ESP_CONSOLE_UART_NONE

    // Configure BTstack for ESP32 VHCI Controller
    btstack_init();

    // hci_dump_init(hci_dump_embedded_stdout_get_instance());

    // Must be called before uni_init()
    uni_platform_set_custom(get_arduino_platform());

    // Init Bluepad32.
    uni_init(0 /* argc */, NULL /* argv */);

    // Does not return.
    btstack_run_loop_execute();
#if !CONFIG_AUTOSTART_ARDUINO
    return 0;
#endif  // !CONFIG_AUTOSTART_ARDUINO
}

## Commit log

2025-09-26 checkpoint 1 and kicad
    [Spy.kicad_pcb, Spy.kicad_sch]
2025-10-04 fully working controller and motors
2025-10-05 kicad libraries
    [GP2Y0A21YK0F.step, L298N.step, QTR-8A.step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]
2025-10-07 updated movement so left joystick -> left motor and right joystick -> right motor. Much simpler code and gives the most rotational control
2025-10-09 schematic (1) :D
    [Spy.kicad_sch]
2025-10-11 pcb edited
    [Spy.kicad_pcb]
2025-10-11 implemented automation switch, added future plans
2025-10-11 fix please
    [Spy.kicad_sch]
2025-10-11 added skeleton code for all sensors. All pins are placeholders.
2025-10-13 implemented all sensors, separated methods based on purpose (helper, debug, mode, setup), fixed style
    [arduino_main.cpp]
2025-10-16 new pcb
    [Spy.kicad_pcb]
2025-10-16 first attempt at line follow automation, added.... documentation, alternative movement method to compare, movement helper to simplify coding, wifi integration to monitor wirelessly, invert sensor hel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
    [arduino_main.cpp]
2025-10-18 DRV8871 driver and pin rewiring
    [3190.step, Spy.kicad_pcb, Spy.kicad_sch]
2025-10-18 PID implemented
2025-10-19 FABIAN'S ALGORITHIM 🔥🔥
2025-10-22 rewired some stuff
    [Spy.kicad_pcb, Spy.kicad_sch]
2025-10-27 changed algo to work with 2 sensors
2025-10-30 Reverted and fixed version of code. Some minor PCB updates
    [Spy.kicad_pcb, Spy.kicad_sch]
2025-11-01 updated color automation for a 'NONE' option if its not rgb. This will help avoid stopping on white, black, or any other color
    [arduino_main.cpp]
2025-11-01 had error, should be able to build
    [arduino_main.cpp]
2025-11-02 removed wifi and invertsensors, reformatted entire file to group methods and variables together, all sensors and motors working, color automation completed
2025-11-03 Initialized in wrong location
    [arduino_main.cpp]
2025-11-09 fixed alert, updated all loops to use delay so background tasks can run properly
    [arduino_main.cpp]
2025-11-12 angle and collection servo implementation
2025-11-12 right pin incorrectly initialized
2025-11-13 fixed servo code
    [Spy-NPTH-drl.gbr, Spy-NPTH-drl_map.gbr, Spy-NPTH.drl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]
